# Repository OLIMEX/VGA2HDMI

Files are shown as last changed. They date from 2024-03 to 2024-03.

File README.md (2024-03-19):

# VGA2HDMI
VGA to HDMI converter

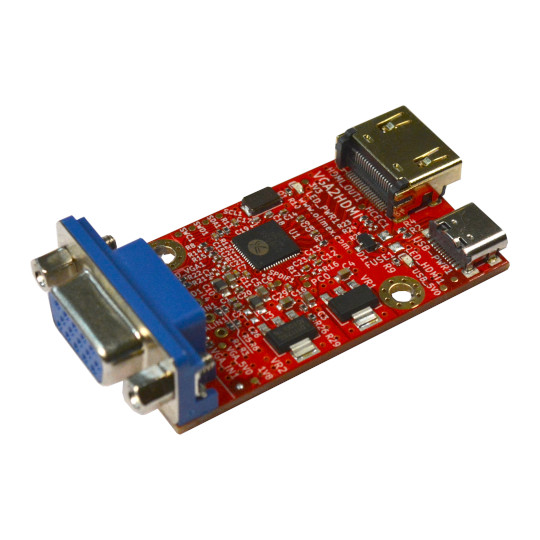
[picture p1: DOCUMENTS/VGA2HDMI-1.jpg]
VGA2HDMI-1


## Features

* VGA input connector
* HDMI output connector
* USB-C for power supply
* Power supply status LED
* VGA signal status LED
* HDMI signal status LED
* Dimensions 51x33mm
* 2 mount holes

## Licenses

* Hardware is released under CERN Open Hardware Licence Version 2 - Strongly Reciprocal, all silkscreen credits to Olimex should remain;
* Documentation is released under CC BY-SA 4.0

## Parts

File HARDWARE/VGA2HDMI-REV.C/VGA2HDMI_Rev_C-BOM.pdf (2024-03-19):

VGA2HDMI_Rev_C_BOM | 12/15/2023
Qty | Designation | Footprint | Designator
1 | HDR15-3.08-14.5T/VGA15/14.5mm | VGA15-F(HDR15-3.08-14.5T)_DrillSlot | VGA_IN1
2 | 5.1k/1%/R0402 | R_0402_5MIL_DWS | R2,R4
1 | HDMI-SWM-19 | HDMI-SWM-19_Paste | HDMI_OUT1
1 | USB-C-16P-F(A40-00119-A52-12) | USB2.0_TYPE-C(A40-00119-A52-12)_Paste | USB-PWR1
1 | NA(4.7k/R0402) | R_0402_5MIL_DWS | R11
1 | 0R/R0402/Board_Mounted | R_0402_5MIL_0R(Board_Mounted) | R17
2 | IND/600OHM/2A/ UPZ2012E-601-2R0TF/L0805 | L_0805_5MIL_DWS | L4,L3
2 | 33pF/50V/5%/C0G/C0402 | C_0402_5MIL_DWS | C18,C19
3 | 2.2k/R0402 | R_0402_5MIL_DWS | R8,R10,R9
3 | 47nF/50V/10%/X7R/C0402 | C_0402_5MIL_DWS | C21,C22,C20
1 | 1k/1%/R0402 | R_0402_5MIL_DWS | R7
5 | NA(GG0402052R542P) | D_0402_5MIL_DWS | TVS5,TVS3,TVS4,TVS2,TVS1
7 | 75R/1%/R0402 | R_0402_5MIL_DWS | R12,R19,R13,R15,R20,R14,R18
5 | 22uF/6.3V/20%/X5R/C0603 | C_0603_5MIL_DWS | C5,C10,C3,C4,C29
1 | LD1117AG-AD-AA3-A-R | SOT223 | VR2
1 | CH213K(SOT23-3) | SOT23-3 | D1
1 | NA(22uF/6.3V/20%/X5R/C0603) | C_0603_5MIL_DWS | C26
1 | Q24.576MHz/20pF/20ppm/2P/5x3.2mm | HCX-4S_2Pins_5.0x3.2mm_TEST | Q1
1 | NA(1nF/C0402) | C_0402_5MIL_DWS | C24
12 | 100nF/10V/20%/X5R/C0402 | C_0402_5MIL_DWS | C12,C17,C14,C9,C11,C13,C8,C7, C15,C23,C6,C16
2 | NA(10k/R0402) | R_0402_5MIL_DWS | R25,R16
1 | 220R/1%/R0402 | R_0402_5MIL_DWS | R29
8 | 10k/R0402 | R_0402_5MIL_DWS | R22,R3,R1,R6,R21,R23,R5,R24
1 | CV8986(QFN56_7x7mm) | QFN56_7x7_Pitch_0.4mm_EPad_5.4x5.4mm | U1
3 | LED/RED/0603 | LED_0603_KA | LED_VGA1,LED_PWR1,LED_HDMI1
1 | 100R/1%/R0402 | R_0402_5MIL_DWS | R26
2 | 4.7uF/X5R/20%/10V/C0402 | C_0402_5MIL_DWS | C1,C2
1 | LD1117AG-33-AA3-A-R | SOT223 | VR1
1 | NA(FSMD035-1206) | FUSE-1206 | FUSE1
1 | NA(HN1x2(SMD)_H-WX-1x2-LF) | HN1x2(SMD)_H-WX-1x2-LF | PWR1

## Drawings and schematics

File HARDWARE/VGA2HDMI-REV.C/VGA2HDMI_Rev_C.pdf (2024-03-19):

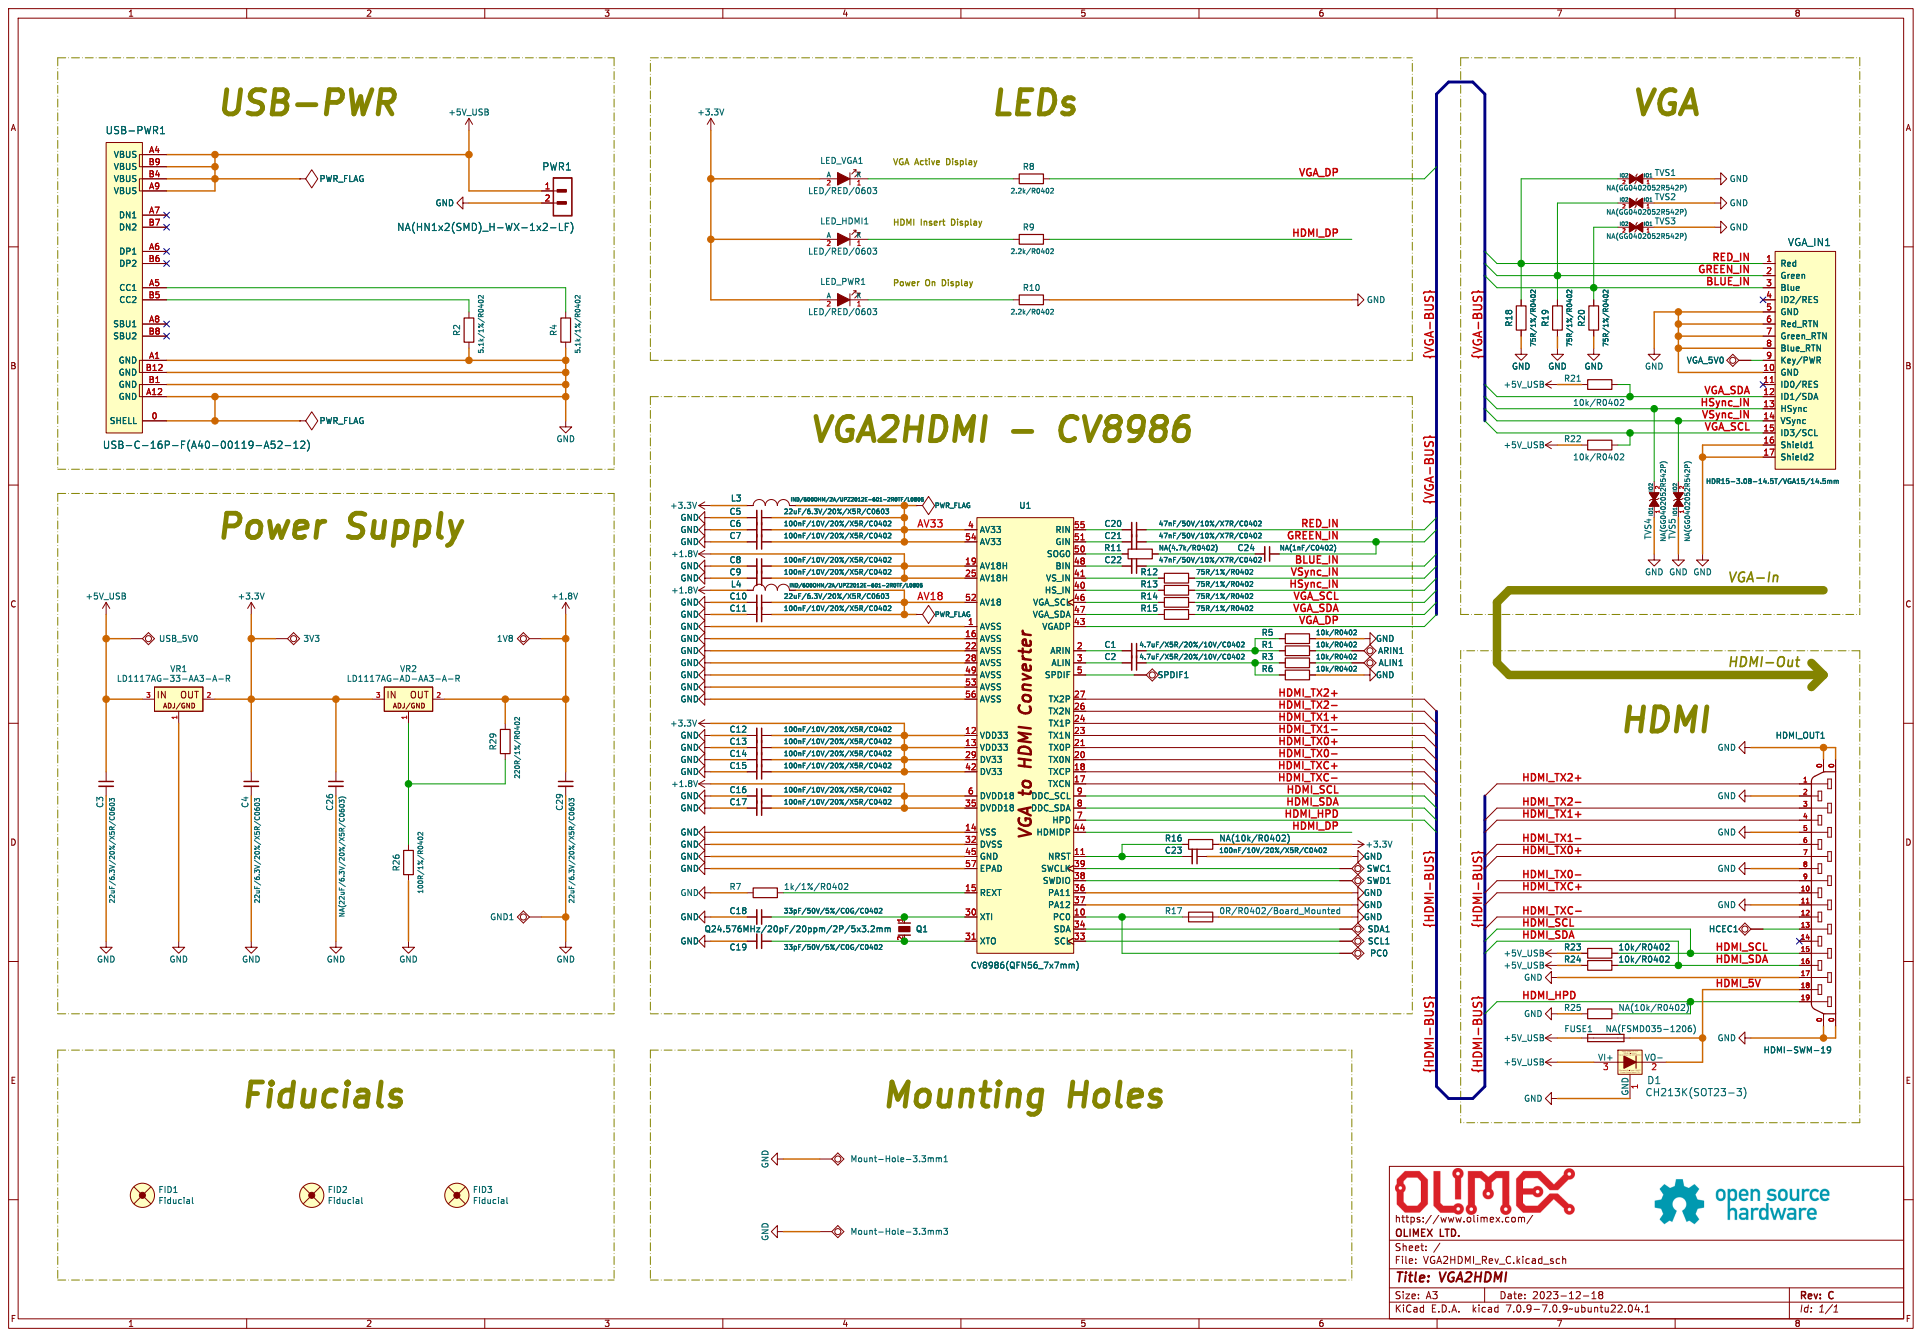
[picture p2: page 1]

VGA Active Display LEDs

2PWR1 NA(HN1x2(SMD)_H-WX-1x2-LF)

HDMI-Out Power Supply

Mount-Hole-3.3mm1 GND GND GND

Id: 1/1 Title: VGA2HDMI File: VGA2HDMI_Rev_C.kicad_sch Sheet: / OLIMEX LTD. https://www.olimex.com/

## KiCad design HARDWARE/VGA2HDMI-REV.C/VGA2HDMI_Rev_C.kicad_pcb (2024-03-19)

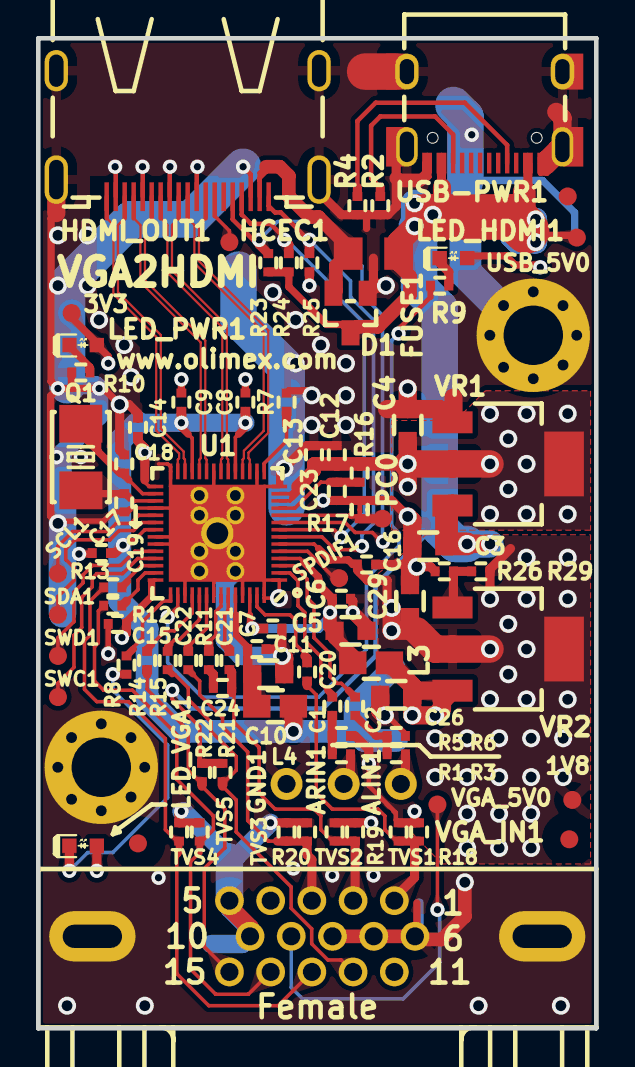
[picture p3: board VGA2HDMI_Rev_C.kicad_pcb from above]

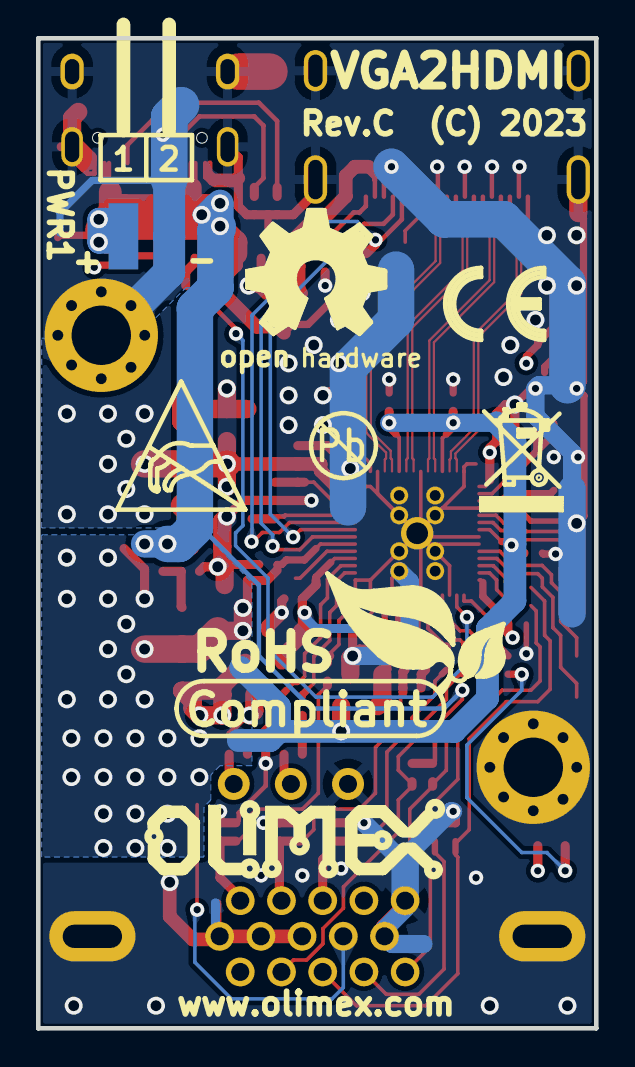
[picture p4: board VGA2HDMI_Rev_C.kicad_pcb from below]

Board: 4 copper layers, 31.0 x 55.0 mm, 99 parts (8 on the bottom side), 60 nets.

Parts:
1V8, 3V3: TESTPAD; TESTPAD_40-ROUND
ALIN1: TESTPAD; TEST_PAD_40x70_Round
ARIN1: TESTPAD; TEST_PAD_40x70_Round
C1, C2: 4.7uF/X5R/20%/10V/C0402; C_0402_5MIL_DWS
C3, C4, C5, C10, C29: 22uF/6.3V/20%/X5R/C0603; C_0603_5MIL_DWS
C6, C7, C8, C9, C11, C12, C13, C14, C15, C16, C17, C23: 100nF/10V/20%/X5R/C0402; C_0402_5MIL_DWS
C18, C19: 33pF/50V/5%/C0G/C0402; C_0402_5MIL_DWS
C20, C21, C22: 47nF/50V/10%/X7R/C0402; C_0402_5MIL_DWS
C24: NA(1nF/C0402); C_0402_5MIL_DWS
C26: NA(22uF/6.3V/20%/X5R/C0603); C_0603_5MIL_DWS
D1: CH213K(SOT23-3); SOT23-3
FID1, FID2: Fiducial; Fiducial1x3
FID3: Fiducial; Fiducial1x3_Paste
FUSE1: NA(FSMD035-1206); FUSE-1206
GND1: TESTPAD; TEST_PAD_40x70_Round
HCEC1: TESTPAD; TESTPAD_40-ROUND
HDMI_OUT1: HDMI-SWM-19; HDMI-SWM-19_Paste
L3, L4: IND/600OHM/2A/UPZ2012E-601-2R0TF/L0805; L_0805_5MIL_DWS
LED_HDMI1: LED/RED/0603; LED_0603_KA
LED_PWR1: LED/RED/0603; LED_0603_KA
LED_VGA1: LED/RED/0603; LED_0603_KA
Logo_OLIMEX_TB-Bottom: Logo_OLIMEX_TB
Mount-Hole-3.3mm1, Mount-Hole-3.3mm3: Mounting_hole_Shield_3.3mm
PC0: TESTPAD; TESTPAD_40-ROUND
PWR1: NA(HN1x2(SMD)_H-WX-1x2-LF); HN1x2(SMD)_H-WX-1x2-LF
Q1: Q24.576MHz/20pF/20ppm/2P/5x3.2mm; HCX-4S_2Pins_5.0x3.2mm_TEST
R1, R3, R5, R6, R21, R22, R23, R24: 10k/R0402; R_0402_5MIL_DWS
R2, R4: 5.1k/1%/R0402; R_0402_5MIL_DWS
R7: 1k/1%/R0402; R_0402_5MIL_DWS
R8, R9, R10: 2.2k/R0402; R_0402_5MIL_DWS
R11: NA(4.7k/R0402); R_0402_5MIL_DWS
R12, R13, R14, R15, R18, R19, R20: 75R/1%/R0402; R_0402_5MIL_DWS
R16, R25: NA(10k/R0402); R_0402_5MIL_DWS
R17: 0R/R0402/Board_Mounted; R_0402_5MIL_0R(Board_Mounted)
R26: 100R/1%/R0402; R_0402_5MIL_DWS
R29: 220R/1%/R0402; R_0402_5MIL_DWS
SCL1: TESTPAD; TESTPAD_40-ROUND
SDA1: TESTPAD; TESTPAD_40-ROUND
SPDIF1: TESTPAD; TESTPAD_40-ROUND
SWC1: TESTPAD; TESTPAD_40-ROUND
SWD1: TESTPAD; TESTPAD_40-ROUND
Sign_Antistatic: Sign_Antistatic
Sign_CE: CE_Sign
Sign_OSHW_8x8: Sign_OSHW_8x8
Sign_PB-Free: Sign_PB-Free
Sign_RecycleBin: Sign_RecycleBin; Sign_RecycleBin_1
Sign_RoHS: Sign_RoHS; Sign_RoHS_1
TVS1, TVS2, TVS3, TVS4, TVS5: NA(GG0402052R542P); D_0402_5MIL_DWS
U1: CV8986(QFN56_7x7mm); QFN56_7x7_Pitch_0.4mm_EPad_5.4x5.4mm
USB-PWR1: USB-C-16P-F(A40-00119-A52-12); USB2.0_TYPE-C(A40-00119-A52-12)_Paste
USB_5V0: TESTPAD; TESTPAD_40-ROUND
VGA_5V0: TESTPAD; TESTPAD_40-ROUND
VGA_IN1: HDR15-3.08-14.5T/VGA15/14.5mm; VGA15-F(HDR15-3.08-14.5T)_DrillSlot
VR1: LD1117AG-33-AA3-A-R; SOT223
VR2: LD1117AG-AD-AA3-A-R; SOT223

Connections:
+1.8V: 1V8.1 (Pad), C8.1, C9.1, C16.1, C17.1, C29.1, L4.1, R29.2, U1.6 (DVDD18), U1.19 (AV18H), U1.25 (AV18H), U1.35 (DVDD18), VR2.2 (OUT)
+3.3V: 3V3.1 (Pad), C4.1, C12.1, C13.1, C14.1, C15.1, C26.1, L3.1, LED_HDMI1.2 (A), LED_PWR1.2 (A), LED_VGA1.2 (A), R16.2, U1.12 (VDD33), U1.13 (VDD33), U1.29 (DV33), U1.42 (DV33), VR1.2 (OUT), VR2.3 (IN)
+5V_USB: C3.1, D1.3 (VI+), FUSE1.1, PWR1.1, R21.1, R22.1, R23.1, R24.1, USB-PWR1.A4 (VBUS), USB-PWR1.A9 (VBUS), USB-PWR1.B4 (VBUS), USB-PWR1.B9 (VBUS), USB_5V0.1 (Pad), VR1.3 (IN)
/AV18: C10.1, C11.1, L4.2, U1.52 (AV18)
/AV33: C5.1, C6.1, C7.1, L3.2, U1.4 (AV33), U1.54 (AV33)
/BLUE_IN: C22.1, R20.2, TVS3.2 (IO2), VGA_IN1.3 (Blue)
/GREEN_IN: C21.1, C24.1, R19.2, TVS2.2 (IO2), VGA_IN1.2 (Green)
/HDMI_5V: D1.2 (VO-), FUSE1.2, HDMI_OUT1.18
/HDMI_DP: R9.2, U1.44 (HDMIDP)
/HDMI_HPD: HDMI_OUT1.19, R25.2, U1.7 (HPD)
/HDMI_SCL: HDMI_OUT1.15, R23.2, U1.9 (DDC_SCL)
/HDMI_SDA: HDMI_OUT1.16, R24.2, U1.8 (DDC_SDA)
/HDMI_TX0+: HDMI_OUT1.7, U1.21 (TX0P)
/HDMI_TX0-: HDMI_OUT1.9, U1.20 (TX0N)
/HDMI_TX1+: HDMI_OUT1.4, U1.24 (TX1P)
/HDMI_TX1-: HDMI_OUT1.6, U1.23 (TX1N)
/HDMI_TX2+: HDMI_OUT1.1, U1.27 (TX2P)
/HDMI_TX2-: HDMI_OUT1.3, U1.26 (TX2N)
/HDMI_TXC+: HDMI_OUT1.10, U1.18 (TXCP)
/HDMI_TXC-: HDMI_OUT1.12, U1.17 (TXCN)
/HSync_IN: R13.2, TVS4.2 (IO2), VGA_IN1.13 (HSync)
/RED_IN: C20.1, R18.2, TVS1.2 (IO2), VGA_IN1.1 (Red)
/VGA_DP: R8.2, U1.43 (VGADP)
/VGA_SCL: R14.2, R22.2, VGA_IN1.15 (ID3/SCL)
/VGA_SDA: R15.2, R21.2, VGA_IN1.12 (ID1/SDA)
/VSync_IN: R12.2, TVS5.2 (IO2), VGA_IN1.14 (VSync)
GND: C3.2, C4.2, C5.2, C6.2, C7.2, C8.2, C9.2, C10.2, C11.2, C12.2, C13.2, C14.2, C15.2, C16.2, C17.2, C18.2, C19.2, C23.1, C26.2, C29.2, D1.1 (GND), GND1.1 (Pad), HDMI_OUT1.0 (20), HDMI_OUT1.2, HDMI_OUT1.5, HDMI_OUT1.8, HDMI_OUT1.11, HDMI_OUT1.17, Mount-Hole-3.3mm1.GND1, Mount-Hole-3.3mm3.GND1, PWR1.2, R2.1, R4.1, R5.2, R6.2, R7.1, R10.2, R17.2, R18.1, R19.1, R20.1, R25.1, R26.1, TVS1.1 (IO1), TVS2.1 (IO1), TVS3.1 (IO1), TVS4.1 (IO1), TVS5.1 (IO1), U1.1 (AVSS), U1.14 (VSS), U1.16 (AVSS), U1.22 (AVSS), U1.28 (AVSS), U1.32 (DVSS), U1.36 (PA11), U1.37 (PA12), U1.45 (GND), U1.49 (AVSS), U1.53 (AVSS), U1.56 (AVSS), U1.57 (EPAD), USB-PWR1.0 (SHELL), USB-PWR1.A1 (GND), USB-PWR1.A12 (GND), USB-PWR1.B1 (GND), USB-PWR1.B12 (GND), VGA_IN1.5 (GND), VGA_IN1.6 (Red_RTN), VGA_IN1.7 (Green_RTN), VGA_IN1.8 (Blue_RTN), VGA_IN1.10 (GND), VGA_IN1.16 (Shield1), VGA_IN1.17 (Shield2), VR1.1 (ADJ/GND)
unnamed: ALIN1.1 (Pad), R3.2
unnamed: ARIN1.1 (Pad), R1.2
unnamed: C1.1, R1.1, R5.1
unnamed: C2.1, R3.1, R6.1
unnamed: C24.2, R11.2
unnamed: HCEC1.1 (Pad), HDMI_OUT1.13
unnamed: LED_HDMI1.1 (K), R9.1
unnamed: LED_PWR1.1 (K), R10.1
unnamed: LED_VGA1.1 (K), R8.1
unnamed: C2.2, U1.3 (ALIN)
unnamed: C1.2, U1.2 (ARIN)
unnamed: C22.2, U1.48 (BIN)
unnamed: C21.2, U1.51 (GIN)
unnamed: R13.1, U1.40 (HS_IN)
unnamed: C23.2, R16.1, U1.11 (NRST)
unnamed: PC0.1 (Pad), R17.1, U1.10 (PC0)
unnamed: R7.2, U1.15 (REXT)
unnamed: C20.2, U1.55 (RIN)
unnamed: SCL1.1 (Pad), U1.33 (SCL)
unnamed: SDA1.1 (Pad), U1.34 (SDA)
unnamed: R11.1, U1.50 (SOG0)
unnamed: SPDIF1.1 (Pad), U1.5 (SPDIF)
unnamed: SWC1.1 (Pad), U1.39 (SWCLK)
unnamed: SWD1.1 (Pad), U1.38 (SWDIO)
unnamed: R14.1, U1.46 (VGA_SCL)
unnamed: R15.1, U1.47 (VGA_SDA)
unnamed: R12.1, U1.41 (VS_IN)
unnamed: C18.1, Q1.1, U1.30 (XTI)
unnamed: C19.1, Q1.2, U1.31 (XTO)
unnamed: R4.2, USB-PWR1.A5 (CC1)
unnamed: R2.2, USB-PWR1.B5 (CC2)
unnamed: VGA_5V0.1 (Pad), VGA_IN1.9 (Key/PWR)
unnamed: R26.2, R29.1, VR2.1 (ADJ/GND)

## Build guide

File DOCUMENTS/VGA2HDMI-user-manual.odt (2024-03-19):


VGA2HDMI

User Manual

Rev.1.0 March 2024 olimex.com

# What is VGA2HDMI

VGA2HDMI (https://www.olimex.com/Products/Retro-Computers/VGA2HDMI/open-source-hardware) is an open source hardware board which converts signals from VGA to HDMI. This allow old retro computers, game consoles and devices with VGA output to be displayed on modern displays and TVs with HDMI input.

AgonLight2 (https://www.olimex.com/Products/Retro-Computers/AgonLight2/open-source-hardware), AgonOrigins (https://www.olimex.com/Products/Retro-Computers/AgonOrigins/open-source-hardware) and Cerberus2100 (https://www.olimex.com/Products/Retro-Computers/CERBERUS2100/open-source-hardware) are tested to work with VGA2HDMI (https://www.olimex.com/Products/Retro-Computers/VGA2HDMI/open-source-hardware).

# VGA2HDMI features:

- VGA connector input
- HDMI connector output
- USB-C power supply connector
- Power supply status LED
- VGA signal LED
- HDMI signal LED
- Dimensions are: 51 x 33 mm

# Order codes for VGA2HDMI:

VGA2HDMI (https://www.olimex.com/Products/Retro-Computers/VGA2HDMI/open-source-hardware) VGA2HDMI converter

VGA2HDMI-BOXED (https://www.olimex.com/Products/Retro-Computers/VGA2HDMI-BOXED/open-source-hardware) VGA2HDMI converter in plastic box

USB-CABLE-A-TO-C-1M (https://www.olimex.com/Products/Components/Cables/USB-CABLE-A-TO-C-1M/) USB-A to USB-C cable

CABLE-HDMI-50CM (https://www.olimex.com/Products/Components/Cables/CABLE-HDMI-50CM/) HDMI cable

# HARDWARE

## VGA2HDMI layout:

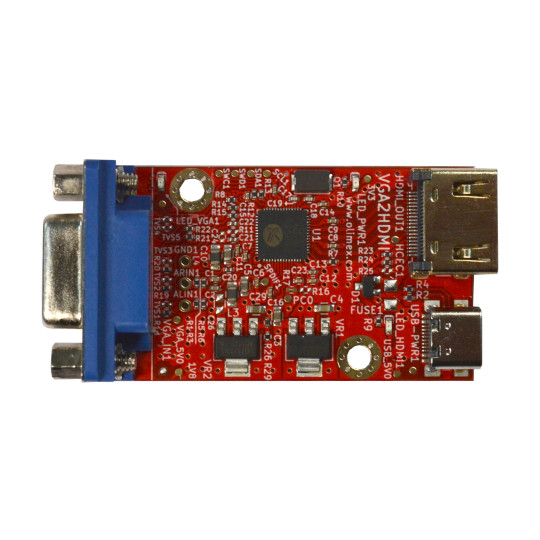
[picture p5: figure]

VGA input

HDMI output

Power supply USB-C

## VGA2HDMI schematics:

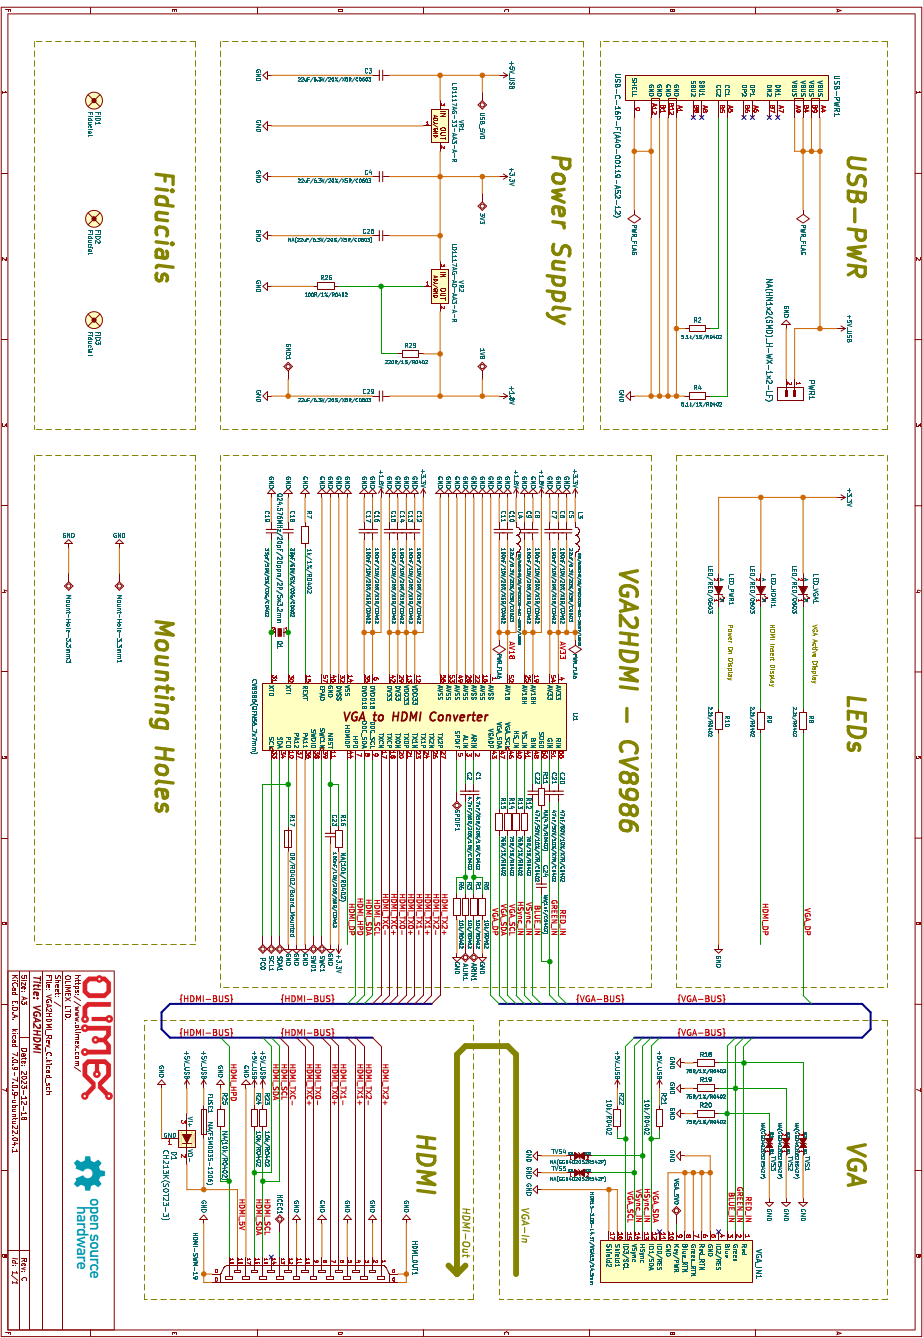
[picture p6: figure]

# Revision History

Revision 1.0 March 2024

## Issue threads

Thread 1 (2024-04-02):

VGA text output via HDMI?

techsurrusr, 2024-04-02:
The standard text mode for VGA DOS was 80 by 25 characters, which translated to a resolution of 720 by 400 (characters of 9 by 16 pixels), does the VGA2HDMI support this and hopefully then also that it will output BIOS splash screen as well?

8192K, 2024-07-10:
Let's give this question a push!

8192K, 2024-07-10:
those DOS text mode resolutions usually all came in 70Hz. If you have a PC with VGA output, the BIOS splash, the POST screen as well as anything that's not at 640x480 should be a text mode resolution. If you can see converted output there, the adapter should work.

DanKoloff, 2024-07-10:
Well it shows nothing I tested with two older PCs and two different TVs with HDMI. Video output comes at GRUB loader selection and the OS loading. No BIOS logo shown, and if I disable logo in BIOS neither do I see see POST messages. Nothing comes before GRUB if I use VGA2HDMI.

8192K, 2024-07-10:
Alright, then it does not work. Thanks for testing!
I, however, you could make this work, then you'd all of a sudden gain a whole new group of potential customers :) (retro gamers)

DanKoloff, 2024-07-10:
Yeah, I don't think the chip inside supports it. Tho we have a lot of retro gamers fans already, and we manufacture a number of retro computers, check here: https://www.olimex.com/Products/Retro-Computers/

sonic74, 2024-11-16:
Maybe the attached monitor just doesn't support >60 Hz
Is LED_VGA1 lit?

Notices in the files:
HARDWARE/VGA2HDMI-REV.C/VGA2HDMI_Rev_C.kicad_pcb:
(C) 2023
